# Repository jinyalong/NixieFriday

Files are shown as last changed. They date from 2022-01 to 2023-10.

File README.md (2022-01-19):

# NixieFriday

日志：www.codefriday.cn

Nixie tubes clock with six IN-14

DIY成本预计在1k左右~，有170V电压，无电子基础的！

电阻容封装统一采用0603

# 简单介绍

## 硬件

硬件部分由Altium Designer20.0设计

主要分为以下模块：

+ Power：Type输出5V，降压输出3.3V为芯片等供电
+ Boost电路：5V升压170V电路（超小体积，效率理论在85以上）
+ Buzzer：蜂鸣器模块，提供一些类似于闹钟发声的功能
+ RTC模块：使用一颗DS3231SN实时时钟芯片，精准走时，一年误差一分钟
+ MCU：ESP32-Wroom-E 16MB，板载天线，自带wifi蓝牙
+ 红外接收：VS1838B
+ 冒号管：4mm氖泡
+ RGB背光：WS2812C/W 

+ 辉光管显示：来自83年一月份生产同批CCCP&OTK认证的IN-14全新辉光管6支
+ OLED显示屏：0.96英寸，128x64

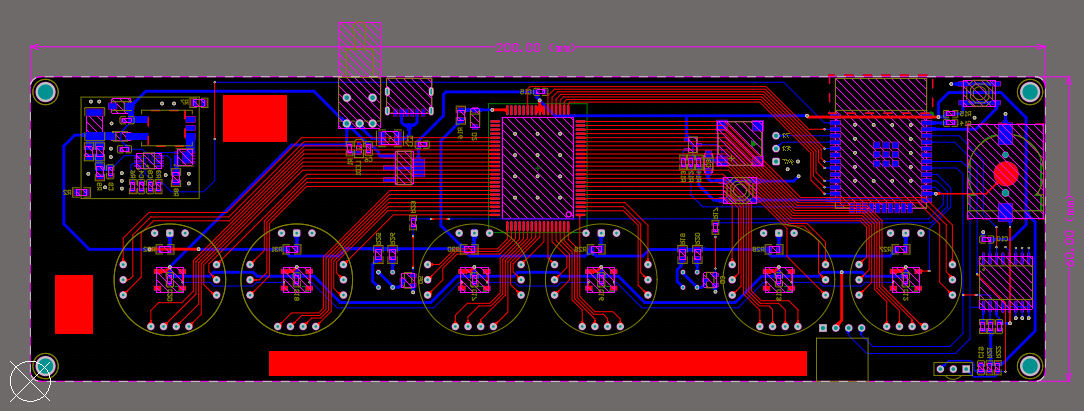
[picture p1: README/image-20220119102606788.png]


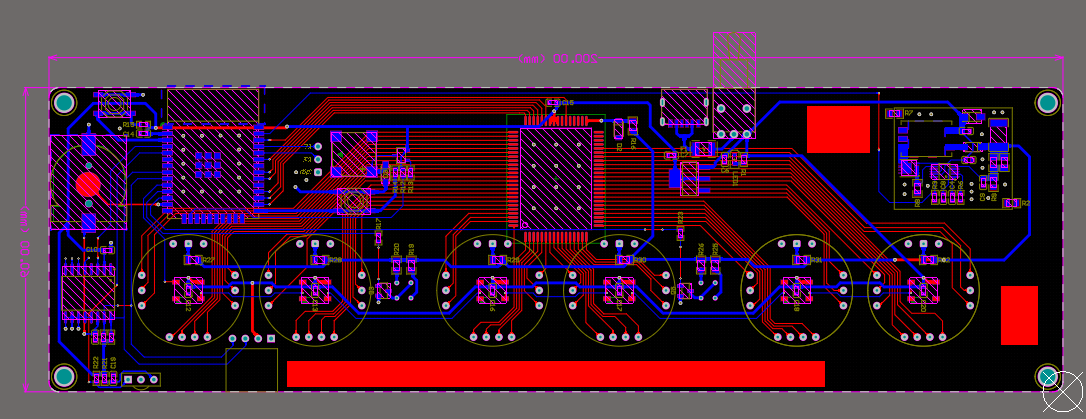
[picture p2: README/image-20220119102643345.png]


3D渲染图：

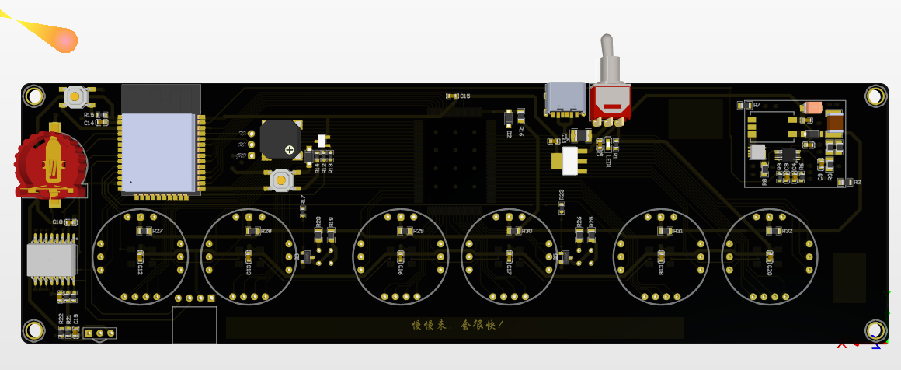
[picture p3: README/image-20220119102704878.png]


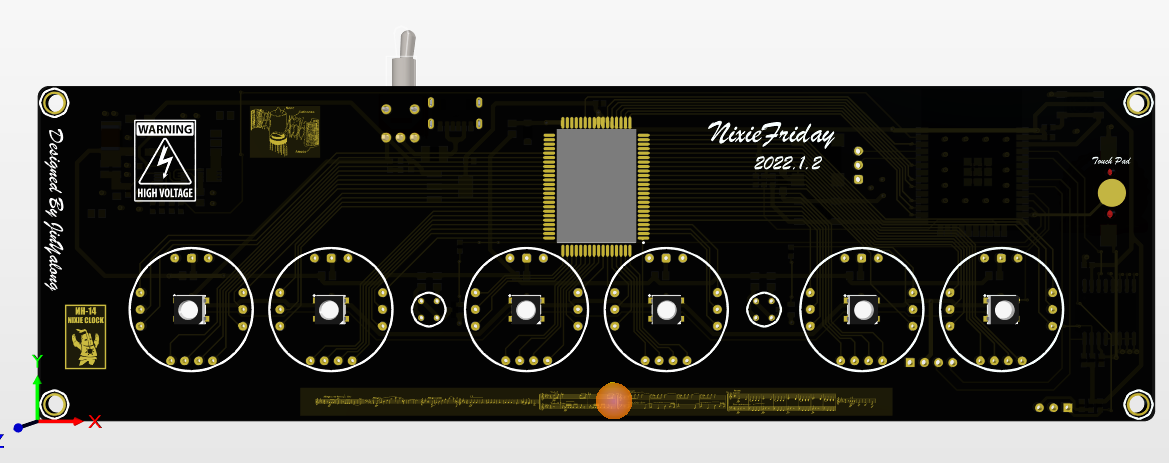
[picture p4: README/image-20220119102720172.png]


## 软件

软件部分采用了MicroPython驱动硬件，基本和python语法一样，软件部分等待完善后开源

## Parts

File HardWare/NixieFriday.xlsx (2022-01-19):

Comment | Description | Designator | Footprint | LibRef | Quantity
BUZ | 蜂鸣器 | B1 | BUZ-SMD_4P-L8.5-W8.5-TL | BUZ | 1
BS-12-B3AA003 | 纽扣电池 | BT1 | BAT-SMD_BS-12-B3AA011 | BS-12-B3AA003 | 1
100uf | 极性电容 | C1 | CAP-SMD_L3.2-W1.6-RD | Cap_pol | 1
100nf | 电容 | C2, C3, C8, C10, C11, C12, C13, C14, C16, C17, C18, C20 | C0603 | Cap | 12
1uf | 电容 | C4 | C0603 | Cap | 1
1uf/250V | 电容 | C5 | C1812 | Cap | 1
10uf | 电容 | C6, C7, C19 | C0603 | Cap | 3
10pf/50V | 电容 | C9 | C0603 | Cap | 1
100pf | 电容 | C15 | C0603 | Cap | 1
E1J | E1J | D1, D3 | SOD-123FL_L2.7-W1.8-LS3.8-RD | E1J | 2
75V/0.5W | Schottky Rectifier | D2 | 75V二极管 | Diode 10TQ040 | 1
DOT | 4x10mm氖泡 | Dot1-1, Dot1-2, Dot2-1, Dot2-2 | NEON | DOT | 4
F1210 |  | F1 | F1210 | F1210 | 1
IRM-56384 | 红外接收管 | IR1 | OPTO-TH_IRM-56384 | IRM-56384 | 1
1x4p | 2.54mm | J1 | 1X4P_2.54_弯 | 1x4p | 1
1x3p |  | J2 | 1X3P | 1x3p | 1
LED | LED发光管 | LED1 | LED0603 | LED | 1
ИН-14 |  | N1, N2, N3, N4, N5, N6 | NH_14_PIN | ИН-14 | 6
TPN1R603PL,L1Q |  | Q1 | PG-TSDSON-8_L3.3-W3.3-P0.65-BL | TPN1R603PL,L1Q | 1
SS8550G |  | Q2 | SS8550G | SS8550G | 1
A42 | NPN General Purpose Amplifier | Q3, Q5 | SOT-23-3 | 2N3904 | 2
10k | 电阻 | R1, R10, R11, R12, R14, R15, R22 | R0603 | R | 7
0 | 电阻 | R2, R7 | R0805 | R | 2
1M | 电阻 | R3 | R0603 | R | 1
10M | 电阻 | R4, R5 | R0805 | R | 2
470k | 电阻 | R6 | R0603 | R | 1
0.02 | 电阻 | R8 | R0805 | R | 1
36k | 电阻 | R9 | R0805 | R | 1
1k | 电阻 | R13 | R0603 | R | 1
240k | 电阻 | R16, R19, R20, R25, R26 | R0805 | R | 5
33k | 电阻 | R17, R23 | R0603 | R | 2
100 | 电阻 | R21 | R0603 | R | 1
20k | 电阻 | R27, R28, R29, R30, R31, R32 | R0805 | R | 6
1TS001G-1500-1700 |  | RST1, RST2 | SW-SMD_4P-L5.1-W5.1-P3.70-LS6.5-TL-2 | 1TS001G-1500-1700 | 2
ST-0-102-C03-N003-RS |  | SW1 | 钮子开关 | 钮子开关 | 1
TTRN-060S-013-T |  | T1 | TTRN-060S-013 | TTRN-060S-013-T | 1
touch_pad |  | touch1 | TOUCH_PAD | touch_pad | 1
MAX668EUB+ |  | U1 | MAX668_MSOP-10 | MAX668EUB+ | 1
TYPEC-250D-BCP6 | TypeC母座 | U2 | USB-C-SMD_TYPEC-250D-BCP6 | TYPEC-250D-BCP6 | 1
AMS1117-3.3 |  | U3 | SOT-223 | AMS1117-3.3 | 1
HV57708PG |  | U4 | PQFP80 | HV57708PG | 1
DS3231SN | RTC芯片 | U5 | DS3231_SOIC-16 | DS3231SN | 1
ESP32-WROOM-32E(16MB) |  | U6 | WIFI-SMD_ESP32-WROOM-32E | ESP32-WROOM-32E(16MB) | 1
WS2812C |  | W1, W2, W3, W4, W5, W6 | LED-SMD_4P-L5.0-W5.0-TL_WS2812B-B | WS2812C | 6

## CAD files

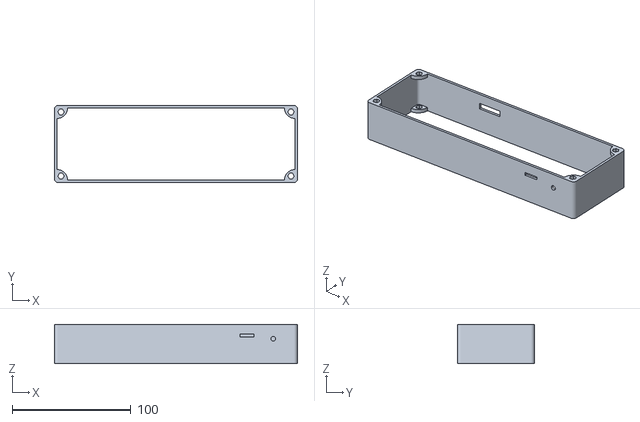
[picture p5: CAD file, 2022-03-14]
3D/外壳.stl
205.0 x 65.0 x 33.0

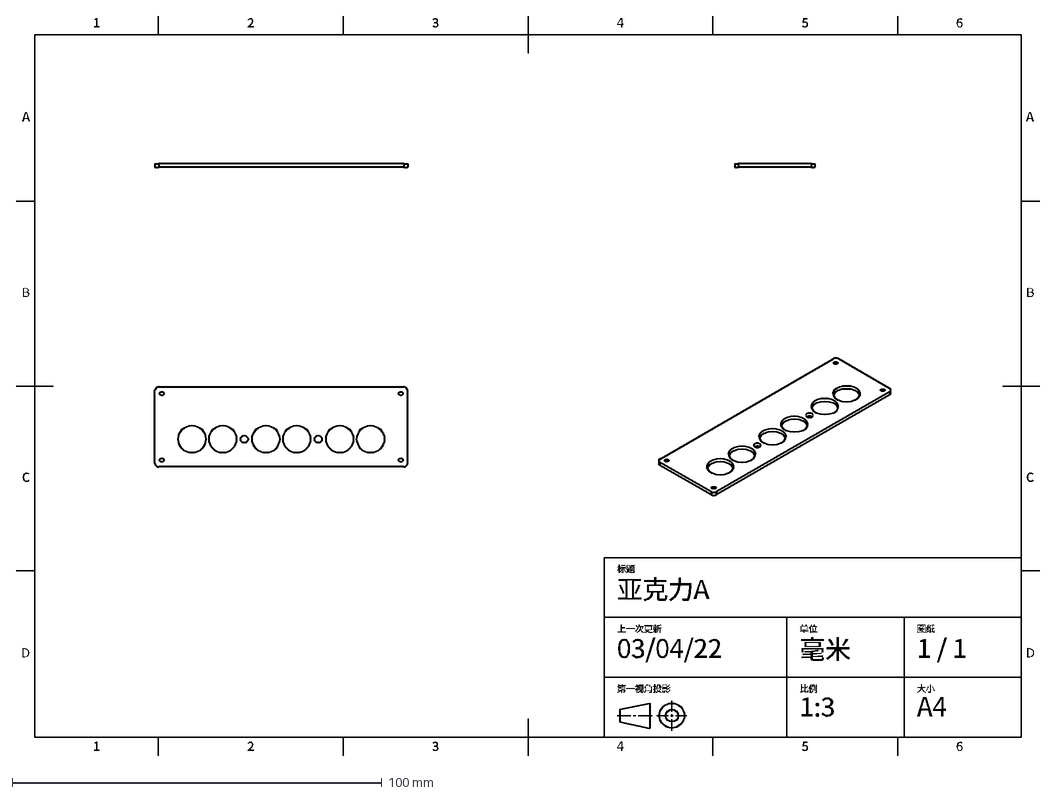
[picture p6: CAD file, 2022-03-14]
3D/亚克力A.dxf
1
2
3
4
5
6
D
C
B
A
标题
亚克力A
上一次更新
03/04/22
单位
毫米
图纸
1 / 1
第一视角投影
比例
1:3
大小
A4

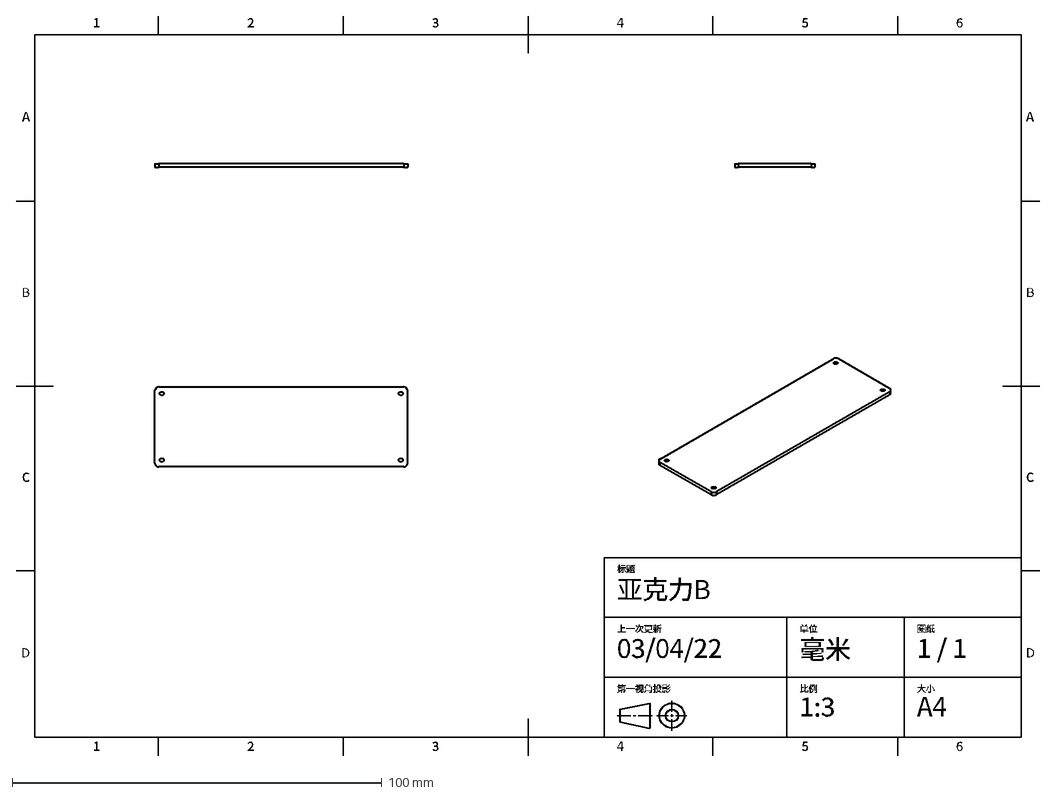
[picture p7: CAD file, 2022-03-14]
3D/亚克力B.dxf
1
2
3
4
5
6
D
C
B
A
标题
亚克力B
上一次更新
03/04/22
单位
毫米
图纸
1 / 1
第一视角投影
比例
1:3
大小
A4

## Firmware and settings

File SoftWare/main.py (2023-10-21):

from DS3231micro import DS3231
from ssd1306 import SSD1306_I2C
from ws2812 import WS2812
from HV57708 import HV57708
from irreciver import IR
from wifimgr import get_connection
from pindef import *
from machine import I2C,Pin,SPI,PWM,Timer,RTC
from umqtt.simple import MQTTClient
import ujson
import utime
import _thread
import machine
import urequests
import json


WEEKDAYS = ['Monday','Tuesday','Wednesday','Thursday','Friday','Saturday','Sunday']

NOW_DAY = -1
NOW_HOUR = -1
NOW_MINUTE = -1
SECOND_COUNT = 0
ALL_FLASH_TIME = 600
TIME_SWITCH = 0

###### 模块定义 ######
dot1 = Pin(DOT1_PIN,Pin.OUT)
dot2 = Pin(DOT2_PIN,Pin.OUT)
i2c = I2C(scl=Pin(SCL_PIN), sda=Pin(SDA_PIN), freq=100000)
spi = SPI(1)
spi.init(baudrate=3200000,mosi=Pin(WS2812_PIN))

ds3231 = DS3231(SCL_PIN, SDA_PIN)
oled = SSD1306_I2C(128,64,i2c,addr=60)
ir = IR(IRM_PIN)
ws2812 = WS2812(spi,led_count=6)
hv_en = Pin(HVEN_PIN,Pin.OUT)
hv57708 = HV57708(0)
dot1_pwm = PWM(dot1)
dot2_pwm = PWM(dot2)

ir_Timer = Timer(1)
clock_Timer = Timer(2)
rtc = RTC()
config = None
mqttClient = None
# 订阅的主题，接收推送的指令消息
topic_sub = None
# 发布的主题，发布自身状态
topic_rel = None

def upload_status(version):
  global mqttClient,hv_en,config,TIME_SWITCH
  dict = {}
  dict['VERSION'] = version;
  dict['HV_EN'] = hv_en.value()
  dict['WS2812'] = config['ws2812']
  dict['TIME_SWITCH'] = TIME_SWITCH
  dict['DOT'] = config['dots']['dot1']
  dict['FLASHTIME'] = config['flashTime']
  dict['STARTSTR'] = config['start_str']
  dict['HV57708']=config['hv57708']
  mqttClient.publish(topic_rel, ujson.dumps(dict))

def mqtt_thread():
  global mqttClient,ir
  while True:
    mqttClient.wait_msg()
    utime.sleep_ms(300)
    
def ir_handler(t):
  global ir
  changed,s,repeat,t_ok = ir.scan()
  if changed == True:
    if s == '*' and repeat > 50:
      upload_status()
    elif s == '#' and repeat > 100:
      machine.reset()
      
def sub_handler(topic, msg): 
  global ws2812,dot1_pwm,dot2_pwm,ALL_FLASH_TIME,hv_en,config,TIME_SWITCH
  args = msg.decode().split('$')
  if args[0] == 'ws2812':
    r = int(args[2])
    g = int(args[3])
    b = int(args[4])
    if args[1] == 'ALL':
      for i in range(0,6):
        config['ws2812'][i] = (r,g,b)
    else:
      index = 5-int(args[1])
      config['ws2812'][index] = (r,g,b)
    ws2812.show(config['ws2812'])
  elif args[0] == 'dot':
    if args[1] == 'ALL':
      if args[2] == 'ON':
        config['dots']['dot1'] = 1023
        config['dots']['dot2'] = 1023
        dot1_pwm.duty(1023)
        dot2_pwm.duty(1023)
      elif args[2] == 'OFF':
        config['dots']['dot1'] = 0

        config['dots']['dot2'] = 0
        dot1_pwm.duty(0)
        dot2_pwm.duty(0)
      elif args[2] == 'FLASH':
        config['dots']['dot1'] = 512
        config['dots']['dot2'] = 512
        dot1_pwm.duty(512)
        dot2_pwm.duty(512)
      else:
        print('非法参数')
    elif args[1] == 'LEFT':
      if args[2] == 'ON':
        config['dots']['dot2'] = 1023
        dot2_pwm.duty(1023)
      elif args[2] == 'OFF':
        config['dots']['dot2'] = 0
        dot2_pwm.duty(0)
      elif args[2] == 'FLASH':
        config['dots']['dot2'] = 512
        dot2_pwm.duty(512)
      else:
        print('非法参数')
    elif args[1] == 'RIGHT':
      if args[2] == 'ON':
        config['dots']['dot1'] = 1023
        dot1_pwm.duty(1023)
      elif args[2] == 'OFF':
        config['dots']['dot1'] = 0
        dot1_pwm.duty(0)
      elif args[2] == 'FLASH':
        config['dots']['dot1'] = 512
        dot1_pwm.duty(512)
      else:
        print('非法参数')
    else:
      print('非法参数')
  elif args[0] == 'hv57708':
    if args[1] == 'NORMAL':
      hv57708.set_change_mode(0)
      config['hv57708'] = 0
    elif args[1] == 'FLOP':
      hv57708.set_change_mode(1)
      config['hv57708'] = 1
    else:
      print('非法参数')
  elif args[0] == 'FLASHTIME':
    if args[1] == 'SHORT':
      config['flashTime'] = 5
      ALL_FLASH_TIME = 300
    elif args[1] == 'LONG':
      config['flashTime'] = 10
      ALL_FLASH_TIME = 600
    elif args[1] == 'VERYLONG':
      config['flashTime'] = 30
      ALL_FLASH_TIME = 1800
    else:
      print('非法参数')
  elif args[0] == 'STARTSTR':
    if len(args[1]) == 6 and args[1].isdigit() == True:
      config['start_str'] = args[1]
    else:
      print('非法参数')
  elif args[0] == 'HIGHVOLTAGEBOOST':
    if args[1] == 'ON':
      hv_en.value(1)
    elif args[1] == 'OFF':
      hv_en.value(0)
    else:
      print('非法参数')
  elif args[0] == 'RESET':
    machine.reset()
  elif args[0] == 'UPLOAD_STATUS':
    version = int(args[1])
    upload_status(version)
  elif args[0] == 'TIME_SWITCH':
    _index = int(args[1])
    TIME_SWITCH ^= (1 << _index)
    config['time_switch'] = TIME_SWITCH
  else:
    print('非法参数')
  
  with open("config.json",'w') as f:
    f.write(ujson.dumps(config))

def reset_time():
  global ds3231,rtc,NOW_DAY,config
  url = 'http://quan.suning.com/getSysTime.do'
  res=urequests.get(url).text
  print(res)
  j=json.loads(res)
  t2_date = j['sysTime2'].split()[0] #日期
  t2_time = j['sysTime2'].split()[1] #时间
  ds3231.setDate([int(x) for x in t2_date[2:].split('-')])   #设置初始日期年、月、日
  ds3231.setTime([int(x) for x in t2_time.split(':')])   #设置初始时间时、分、秒
  rtc.init(ds3231.getDateTime())
  config['last_day'] = NOW_DAY
  with open("config.json",'w') as f:
    f.write(ujson.dumps(config))
    
def timerSecondFlash(t):
  global SECOND_COUNT,NOW_HOUR,NOW_DAY,ds3231,hv57708,oled,ALL_FLASH_TIME,TIME_SWITCH,dot1,dot2
  SECOND_COUNT += 1
  _tmp = rtc.datetime()
  _date = '-'.join((str(_tmp[0]),str(_tmp[1]),str(_tmp[2])))
  _weekday = _tmp[3]
  _time = ''
  for i in range(4,7):
    if _tmp[i] < 10:
      _time += '0' + str(_tmp[i])
    else:
      _time += str(_tmp[i])
  hv57708.display(_time)
  if SECOND_COUNT == ALL_FLASH_TIME:
    hv57708.prevent_poisoning()
    SECOND_COUNT = 0
  if NOW_DAY != _date:
    NOW_DAY = _date
    reset_time()
    oled.showDateWeekDay(_date,WEEKDAYS[_weekday])
  if NOW_HOUR != _tmp[4]:
    NOW_HOUR = _tmp[4]
    hv_en.value(TIME_SWITCH & (1 << NOW_HOUR))
      
    # 更新RTC
  if NOW_MINUTE != _tmp[5]:
    # 闹钟检测
    if ds3231.alarmTriggert(1):
      print('闹钟1')
    if ds3231.alarmTriggert(2):
      print('闹钟2')
def main():
  global mqttClient,NOW_DAY,config,oled,topic_rel,topic_sub,TIME_SWITCH
  # 1.读取配置文件 并加载一些初始化配置 
  with open("config.json",'r') as load_f:
    config = ujson.load(load_f)
  topic_sub = config['mqtt']['topic_sub']
  topic_rel = config['mqtt']['topic_rel']
  mqttClient = MQTTClient(
    config['mqtt']['clientID'],
    config['mqtt']['mqttServer'],
    config['mqtt']['port'],
    config['mqtt']['user'],
    config['mqtt']['password'],
    60
  )
  NOW_DAY = config['last_day']
  mqttClient.set_callback(sub_handler)
  ALL_FLASH_TIME = config['flashTime']*60
  hv57708.set_change_mode(config['hv57708'])
  TIME_SWITCH = config['time_switch']
  
  # 2.升压模块初始化，清空显示
  hv_en.value(0)
  hv57708.show_nothing()
  dot1_pwm.freq(1)
  dot2_pwm.freq(1)
  dot1_pwm.duty(0)
  dot2_pwm.duty(0)
  utime.sleep_ms(100)
  
  hv_en.value(1)
  hv57708.display_normal(config['start_str'])
  oled.show_powered_by()
  utime.sleep(1)
  oled.showBigWifiLogo()
  ws2812.show(config['ws2812'])
  hv57708.prevent_poisoning()
  
  hv57708.show_nothing()
  dot1_pwm.duty(config['dots']['dot1'])
  dot2_pwm.duty(config['dots']['dot2'])
  
  # 
  esp32_wlan = get_connection(oled)
  try:
    mqttClient.connect()
    oled.mqtt_connecting()
    utime.sleep(2)
    oled.mqtt_connect_res(True)
    mqttClient.subscribe(topic_sub)
  except:
    oled.mqtt_connect_res(False)
    print('mqtt connect false!')  
  _thread.start_new_thread(mqtt_thread,())
  
  if esp32_wlan.isconnected():
    oled.wifi_on()
  rtc.init(ds3231.getDateTime())
  _tmp = rtc.datetime()
  _date = '-'.join((str(_tmp[0]),str(_tmp[1]),str(_tmp[2])))
  _weekday = _tmp[3]
  oled.showDateWeekDay(_date,WEEKDAYS[_weekday])
  ir_Timer.init(period=500,mode=Timer.PERIODIC, callback=ir_handler)
  clock_Timer.init(period=1000, mode=Timer.PERIODIC, callback=timerSecondFlash)
if __name__ == '__main__':
    main()

  

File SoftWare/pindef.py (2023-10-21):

# 所有功能引脚的定义
DOT1_PIN = 26
DOT2_PIN = 27

SCL_PIN = 32
SDA_PIN = 33
RTC_INT_SWQ_PIN = 36

IRM_PIN = 39

WS2812_PIN = 25

HVEN_PIN = 23

HV57708_LE_PIN = 19
HV57708_POL_PIN = 22
HV57708_CLK_PIN = 21
HV57708_DIN4_PIN = 18
HV57708_DIN3_PIN = 17
HV57708_DIN2_PIN = 16
HV57708_DIN1_PIN = 4

BEEP_PIN = 13

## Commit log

2022-01-19 add hardware file
    [AdapterPlate.PcbDoc, NixieFriday.SchDoc, NixieFriday.xlsx]
2023-10-21 add微信xiaochengxu
